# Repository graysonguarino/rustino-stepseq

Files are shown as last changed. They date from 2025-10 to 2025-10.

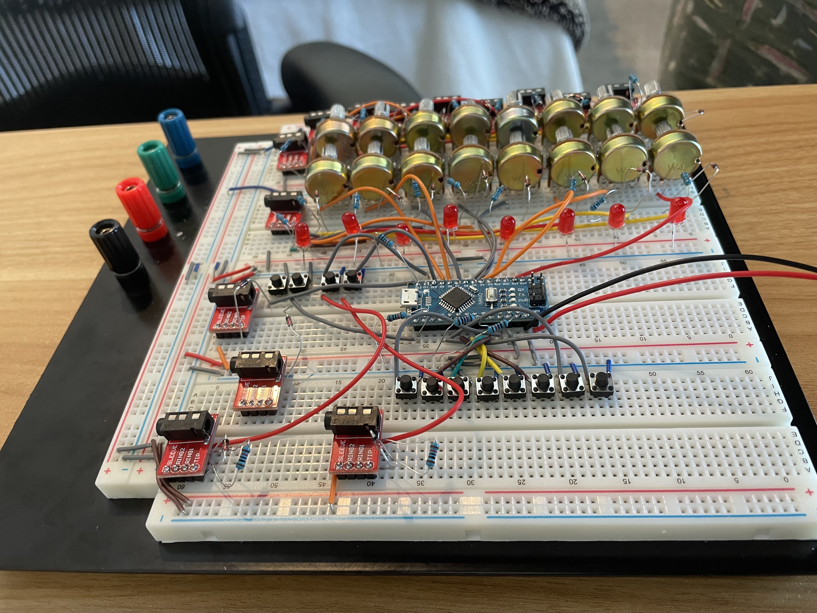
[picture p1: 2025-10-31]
breadboard/back.jpeg

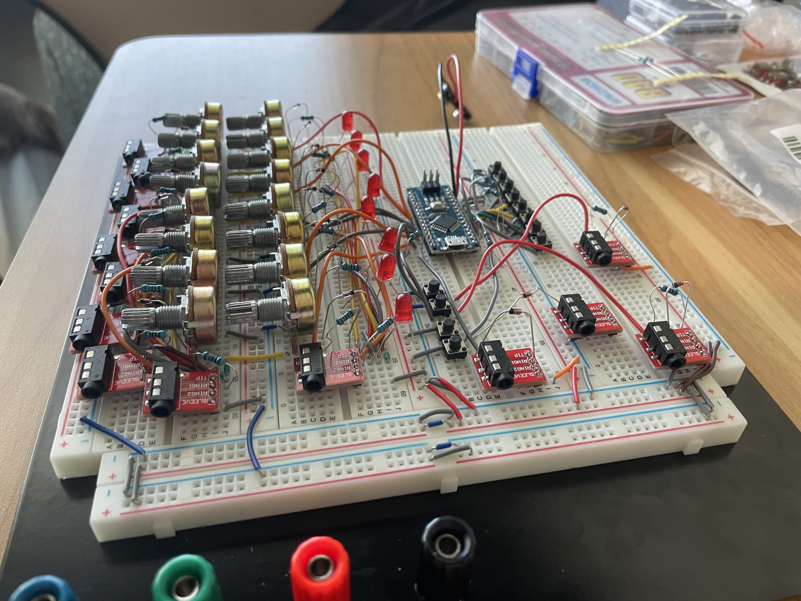
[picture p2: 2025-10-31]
breadboard/side.jpeg

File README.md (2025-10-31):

rustino-stepseq
===============

A step sequencer for Arduino Nano written in Rust. Based on Look Mum No Computer's 
[8 STEP SEQUENCER](https://www.lookmumnocomputer.com/projects#/sequencer-keyboard).

[A demo video of a breadboard of the circuit can be found here](https://www.youtube.com/watch?v=a9vYyX_fQB8).

Rust project for the _Arduino Nano New Bootloader_.

## Update: 10/31/2025 (Happy Halloween! 👻)
This circuit and source code appears to be working! I have now been able to fully
breadboard the circuit and, bar the max 4.6V CV outs (documented in [#2](https://github.com/graysonguarino/rustino-stepseq/issues/2)), 
the step sequencer is working. I cannot confirm 1:1 behavior matching with LOOK MUM
NO COMPUTER's as this uses internal pullups where possible so the logic is slightly 
different.

If you build the circuit from the schematic and something is wrong, please 
view the images and videos in `breadboard/` to see a known-working implementation and 
leave an issue telling me what you found.

## Potential future improvements

* Fix [#2](https://github.com/graysonguarino/rustino-stepseq/issues/2) with a dual opamp.
* Have someone with more electronics experience than me evaluate the schematic.
   * **If you've got an EE background, please contribute if I messed up!**

I think that, as long as this circuit functions, it will be good enough for my needs and I
will not be developing this any further. I have ideas for a more featured step sequencer though,
so once I get the necessary parts in, keep an eye out for that. 👀

## Differences from LOOK MUM NO COMPUTER's

* Internal pullup resistors were used whenever possible, which reduces the BOM.
   * **This means the circuit differs from LMNC's, so don't follow that wiring diagram**
   **unless you change the logic in `peripherals.rs`!**

## Build Notes

* Arduino D12 and D13 require pulldown resistors as D13 is used to light the onboard LED.
   * If you are using buttons instead of an SPDT switch for FWD/BWD, D12 does not need a pulldown
   resistor, but you will need to wire the D12 button to ground instead of +5V and 
   modify `forwards_clock_input` in `Peripherals::new()` to match the settings of 
   `reset_input` and `zero_input`. Since an SPDT switch is used in the schematic, both 
   D12 and D13 will be connected to +5V when the switch is toggled, so the code is set to reflect that.
* Pullup resistors must be wired for Arduino A6 and A7 as these are not GPIO but ADC inputs and
thus do not have internal pullup resistors.
* The diodes on `FWD_CLK_IN` and `BWD_CLK_IN` don't appear to be necessary if you're sure you're
only ever providing a 0->+5V input. Since Eurorack allows for +/-5V CV, the circuit may act funky
if you accidentally feed it a negative voltage without these diodes.

## Build Instructions
1. Install prerequisites as described in the [`avr-hal` README] (`avr-gcc`, `avr-libc`, `avrdude`, [`ravedude`]).

2. Run `cargo build` to build the firmware.

3. Run `cargo run` to flash the firmware to a connected board.  If `ravedude`
   fails to detect your board, check its documentation at
   <https://crates.io/crates/ravedude>.
   * Tip: I have assumed your Arduino is on `/dev/tty.usbserial-210`, but **it likely won't be.** 
   If you're on a *nix system, try running `ls /dev/tty.usbserial*` and if you don't have other 
   devices plugged in besides the Arduino, it's likely that one. Change the `port` entry in 
   `Ravedude.toml` to that value.

4. `ravedude` will open a console session after flashing where you can interact
   with the UART console of your board.

[`avr-hal` README]: https://github.com/Rahix/avr-hal#readme
[`ravedude`]: https://crates.io/crates/ravedude

## License

Currently, this project is being released without license as
I haven't yet discussed license specifics with Sam Battle from
Look Mum No Computer. Once I have discussed it with him, I will
update the license accordingly.

Here is the unofficial license he provided in the source code:

```
//MORE INFO CHECK LOOKMUMNOCOMPUTER.COM
//PLEASE EMAIL ME COMPUTER@LOOKMUMNOCOMPUTER.COM OR LOOKMUMNOCOMPUTER@GMAIL.COM IF ANY QUESTIONS
//ANY MODIFICATIONS PLEASE LET ME KNOW AND I CAN FEATURE ON THE WEBSITE
//OPEN SOURCE. DONT USE IN A PRODUCT OR WHATEVER WITHOUT TALKING TO ME
//SAM BATTLE 2017
//BOOM
```

Boom indeed, Sam. Thanks again for all you do!

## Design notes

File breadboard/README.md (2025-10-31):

# Things on this breadboard which don't match schematic

* Instead of using the 78L05 voltage regulator, I am simply plugging a 9v battery
directly into the `VIN` pin of the Arduino (which can handle 7-12v) and taking the
voltage from the Arduino 5V pin as my positive power rail.
* One of the potentiometers is a 250k pot instead of a 100k pot, but this is only
because I've run out of 100ks.
* TRRS 1/8" jacks are used instead of TS as I had these lying around. It doesn't make
a difference as the two rings are not connected to anything.
* I am using independent buttons instead of a 3-way switch for `RST/ZERO` and `FWD/BWD`
because the switches I have don't fit the breadboard and I don't yet have a way to get
them onto the board without soldering (which I'm trying to avoid for a temporary thing).

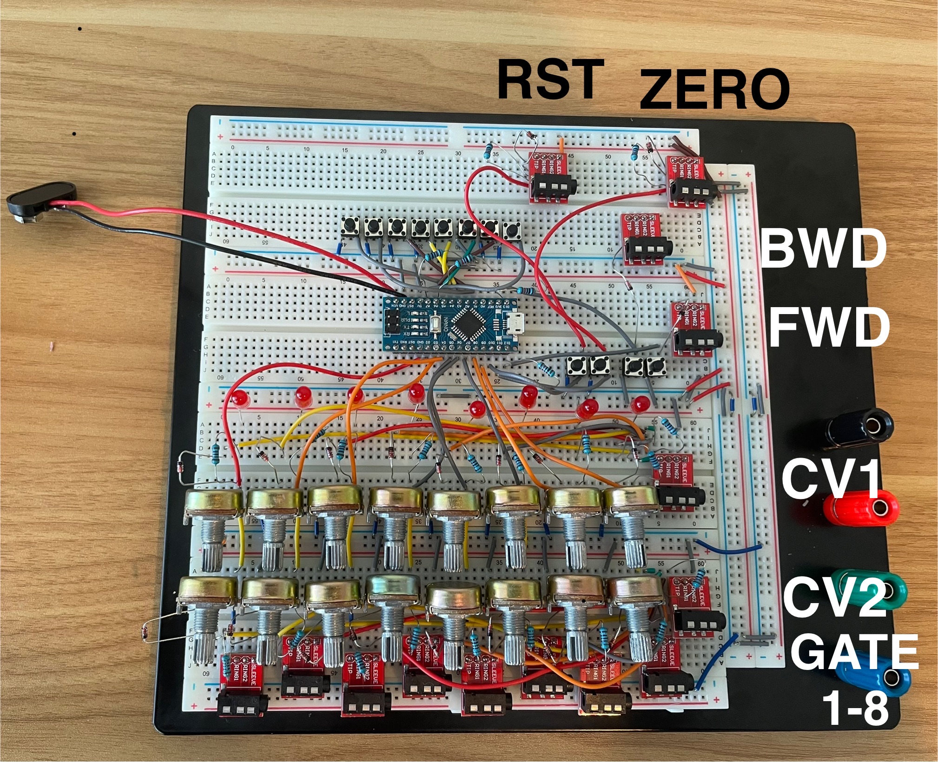
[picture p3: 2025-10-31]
breadboard/top.jpeg

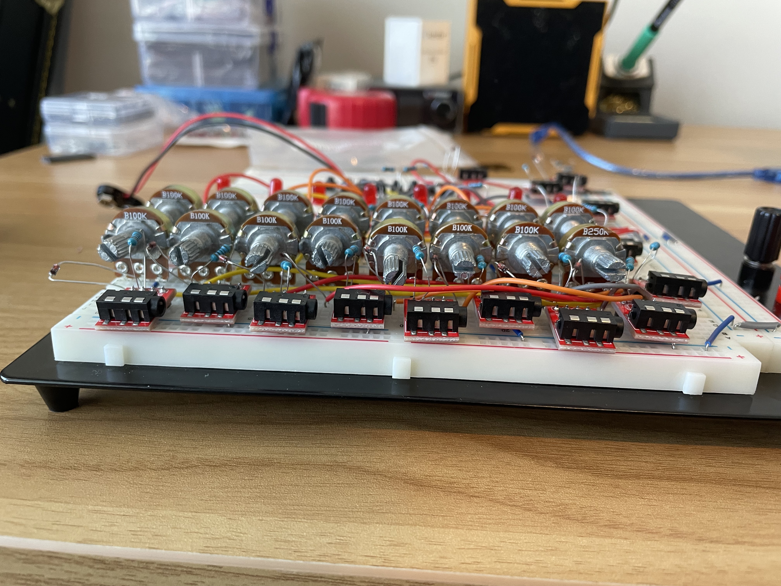
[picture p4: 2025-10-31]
breadboard/front.jpeg

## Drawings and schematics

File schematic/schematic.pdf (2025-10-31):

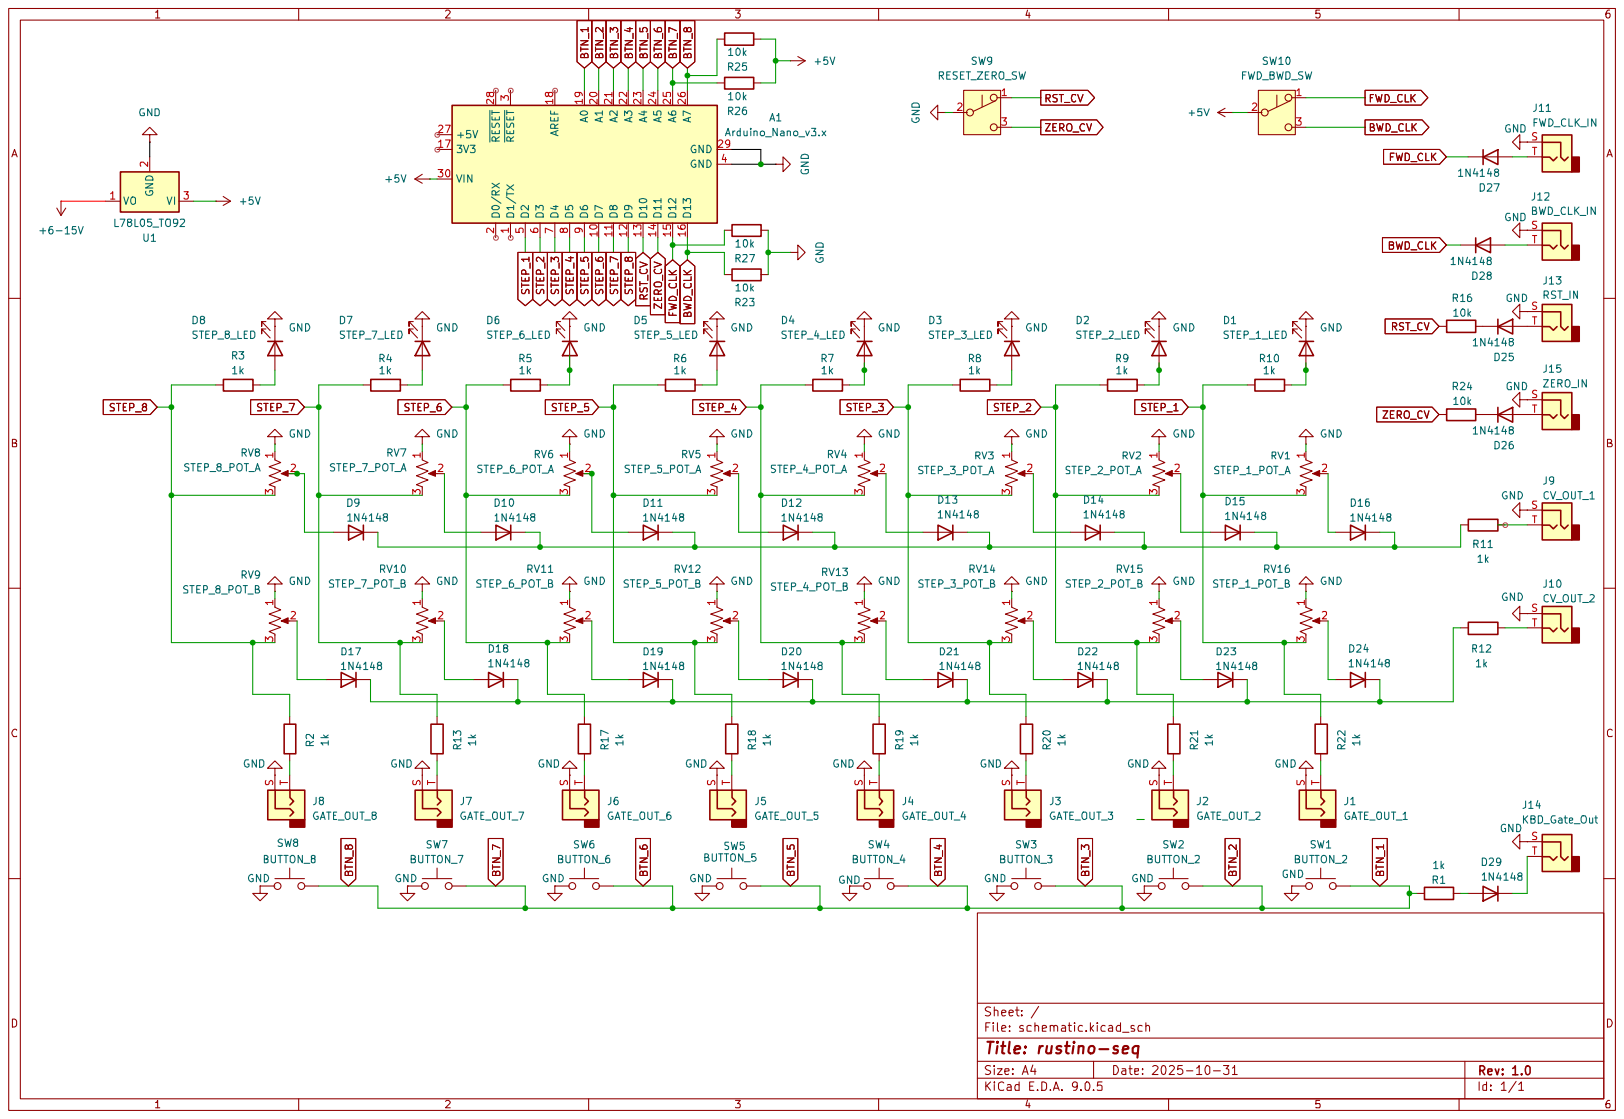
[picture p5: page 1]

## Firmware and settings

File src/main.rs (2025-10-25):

#![no_std]
#![no_main]

mod peripherals;
mod state;

use crate::{peripherals::Peripherals, state::State};
use panic_halt as _;

pub const ADC_HIGH_THRESHOLD: u16 = 1000;
pub const NUM_STEPS: usize = 8;
pub const NUM_BUTTON_INPUTS: usize = NUM_STEPS;
pub const NUM_GATE_OUTPUTS: usize = NUM_STEPS;
pub const MAX_STEP: usize = NUM_STEPS - 1;

#[arduino_hal::entry]
fn main() -> ! {
    let dp = arduino_hal::Peripherals::take().unwrap();
    let peripherals = Peripherals::new(dp);
    let mut state = State::new(peripherals);

    loop {
        state.update();
    }
}

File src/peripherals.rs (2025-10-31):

use crate::{ADC_HIGH_THRESHOLD, NUM_BUTTON_INPUTS, NUM_GATE_OUTPUTS};
use arduino_hal::{
    Adc,
    hal::{self, port::Dynamic},
    pins,
    port::{
        Pin,
        mode::{Input, Output},
    },
};

pub struct Peripherals {
    adc: Adc,
    pub button_inputs: [InputPin; NUM_BUTTON_INPUTS],
    pub gate_outputs: [OutputPin; NUM_GATE_OUTPUTS],
    reset_input: InputPin,
    zero_input: InputPin,
    forwards_clock_input: InputPin,
    backwards_clock_input: InputPin,
}

pub enum InputSelector {
    Button(usize),
    Reset,
    Zero,
    ForwardsClock,
    BackwardsClock,
}

impl Peripherals {
    pub fn new(dp: arduino_hal::Peripherals) -> Self {
        let pins = pins!(dp);
        Self {
            adc: Adc::new(dp.ADC, Default::default()),
            button_inputs: [
                InputPin::GpioPin {
                    pin: pins.a0.into_pull_up_input().forget_imode().downgrade(),
                    on_high: true,
                },
                InputPin::GpioPin {
                    pin: pins.a1.into_pull_up_input().forget_imode().downgrade(),
                    on_high: true,
                },
                InputPin::GpioPin {
                    pin: pins.a2.into_pull_up_input().forget_imode().downgrade(),
                    on_high: true,
                },
                InputPin::GpioPin {
                    pin: pins.a3.into_pull_up_input().forget_imode().downgrade(),
                    on_high: true,
                },
                InputPin::GpioPin {
                    pin: pins.a4.into_pull_up_input().forget_imode().downgrade(),
                    on_high: true,
                },
                InputPin::GpioPin {
                    pin: pins.a5.into_pull_up_input().forget_imode().downgrade(),
                    on_high: true,
                },
                InputPin::AdcPin {
                    pin: hal::adc::channel::ADC6.into_channel(),
                    on_high: true,
                },
                InputPin::AdcPin {
                    pin: hal::adc::channel::ADC7.into_channel(),
                    on_high: true,
                },
            ],
            gate_outputs: [
                OutputPin::OnHigh(pins.d2.into_output_high().downgrade()),
                OutputPin::OnHigh(pins.d3.into_output().downgrade()),
                OutputPin::OnHigh(pins.d4.into_output().downgrade()),
                OutputPin::OnHigh(pins.d5.into_output().downgrade()),
                OutputPin::OnHigh(pins.d6.into_output().downgrade()),
                OutputPin::OnHigh(pins.d7.into_output().downgrade()),
                OutputPin::OnHigh(pins.d8.into_output().downgrade()),
                OutputPin::OnHigh(pins.d9.into_output().downgrade()),
            ],
            reset_input: InputPin::GpioPin {
                pin: pins.d10.into_pull_up_input().forget_imode().downgrade(),
                on_high: false,
            },
            zero_input: InputPin::GpioPin {
                pin: pins.d11.into_pull_up_input().forget_imode().downgrade(),
                on_high: false,
            },
            forwards_clock_input: InputPin::GpioPin {
                pin: pins.d12.into_floating_input().forget_imode().downgrade(),
                on_high: true,
            },
            backwards_clock_input: InputPin::GpioPin {
                pin: pins.d13.into_floating_input().forget_imode().downgrade(),
                on_high: true,
            },
        }
    }

    pub fn is_on(&mut self, selector: InputSelector) -> bool {
        match selector {
            InputSelector::Button(idx) => self.button_inputs[idx].is_on(&mut self.adc),
            InputSelector::Reset => self.reset_input.is_on(&mut self.adc),
            InputSelector::Zero => self.zero_input.is_on(&mut self.adc),
            InputSelector::ForwardsClock => self.forwards_clock_input.is_on(&mut self.adc),
            InputSelector::BackwardsClock => self.backwards_clock_input.is_on(&mut self.adc),
        }
    }
}

pub enum InputPin {
    GpioPin {
        pin: hal::port::Pin<Input, Dynamic>,
        on_high: bool,
    },
    AdcPin {
        pin: hal::adc::Channel,
        on_high: bool,
    },
}

impl InputPin {
    fn is_on(&self, adc: &mut Adc) -> bool {
        match self {
            InputPin::GpioPin { pin, on_high } => {
                let high = pin.is_high();
                if *on_high { high } else { !high }
            }
            InputPin::AdcPin { pin, on_high } => {
                let high = adc.read_blocking(pin) >= ADC_HIGH_THRESHOLD;
                if *on_high { high } else { !high }
            }
        }
    }
}

// Allowing dead code here as the user may need `OnLow` even though we don't use 
// it by default.
#[allow(dead_code)]
pub enum OutputPin {
    OnHigh(Pin<Output>),
    OnLow(Pin<Output>),
}

impl OutputPin {
    pub fn set_on(&mut self) {
        match self {
            OutputPin::OnHigh(pin) => pin.set_high(),
            OutputPin::OnLow(pin) => pin.set_low(),
        }
    }

    pub fn set_off(&mut self) {
        match self {
            OutputPin::OnHigh(pin) => pin.set_low(),
            OutputPin::OnLow(pin) => pin.set_high(),
        }
    }
}

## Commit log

2025-10-25 Add schematic
    [schematic.kicad_sch]
2025-10-27 Bug fixes and refactor, + update README
    [schematic.kicad_sch]
2025-10-28 Fix stacked diodes and D13 on schematic
    [schematic.kicad_sch]
2025-10-28 Pretty up schematic
    [schematic.kicad_sch]
2025-10-31 Make d12 "on high" as it is a switch with same power in as d13
2025-10-31 Fix pull ups and pull downs on schematic
    [schematic.kicad_sch]
2025-10-31 Remove unnessesary (and wrong) resistors on FWD/BWD_CLK_IN
    [schematic.kicad_sch]
2025-10-31 Add diodes to FWD/BWD_CLK_IN
    [schematic.kicad_sch]
2025-10-31 Move diodes from FWD/BWD_CLK_IN to RST/ZERO_IN
    [schematic.kicad_sch]
2025-10-31 Add diodes to all inputs
    [schematic.kicad_sch]
2025-10-31 Cleanup and version schematic
    [schematic.kicad_sch]
